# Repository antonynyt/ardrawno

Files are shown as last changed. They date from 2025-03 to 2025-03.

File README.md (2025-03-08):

# ArDRAWno: Dessinons!

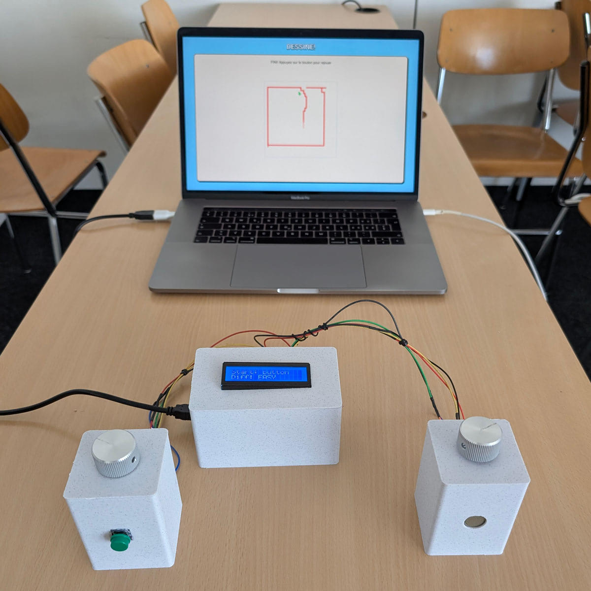
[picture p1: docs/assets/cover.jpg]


Réalisé par Antony Neyret
Option Arduino 2025 – COMEM+

---

## Description

Un jeu collaboratif difficile Ardunio où il faut dessiner une forme donnée. Des petits modules ou controlleurs permettent de dessiner sur le canvas affiché sur une page web.

La difficulté varie selon la communication des joueurs.

## Documentation

Retrouvez la documentation dans le dossier [docs](docs/).

## Photos

https://github.com/user-attachments/assets/9016710e-096b-463b-923a-413ef48c173d

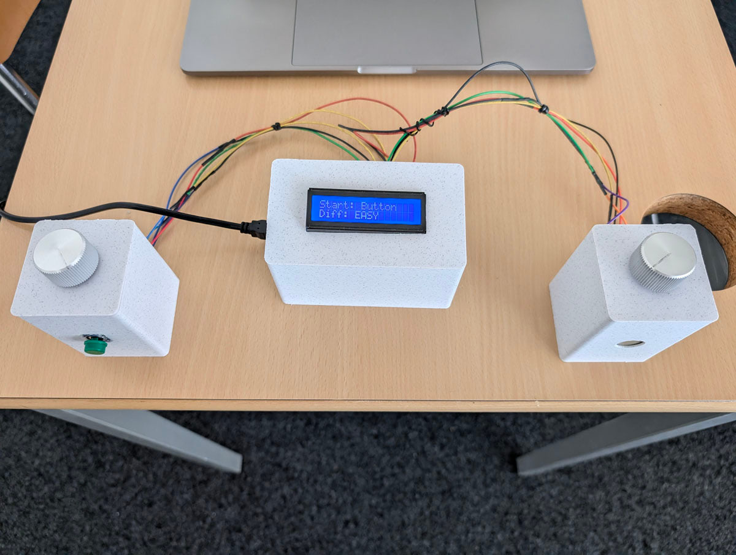
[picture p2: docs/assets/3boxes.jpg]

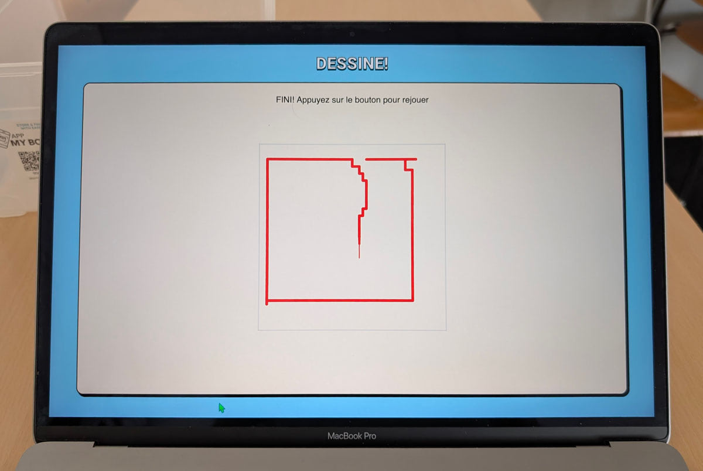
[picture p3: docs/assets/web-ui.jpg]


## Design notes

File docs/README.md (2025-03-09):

# Documentation

## Recherche et conception

Le plus important dans une école et aussi en général, c'est d'avoir une bonne entente avec autrui, communiquer et collaborer. C'est pour cette raison que j'ai eu envie de créer un jeu où il n'y a pas de gagnants ou de compétition mais de l'entraide. Pour renforcer les liens et briser la glace, il faut dessiner en suivant un modèle.

Mon objectif était de proposer une expérience utilisateur originale, volontairement imparfaite mais amusante.

### Inspirations

Je me suis principalement inspiré du jeu _Etch A Sketch_ et de sa méthode particulière de dessiner : deux boutons à tourner qui contrôlent l'axe vertical et horizontal. Je me suis aussi inspiré du jeu _Dessiner c'est gagné_.

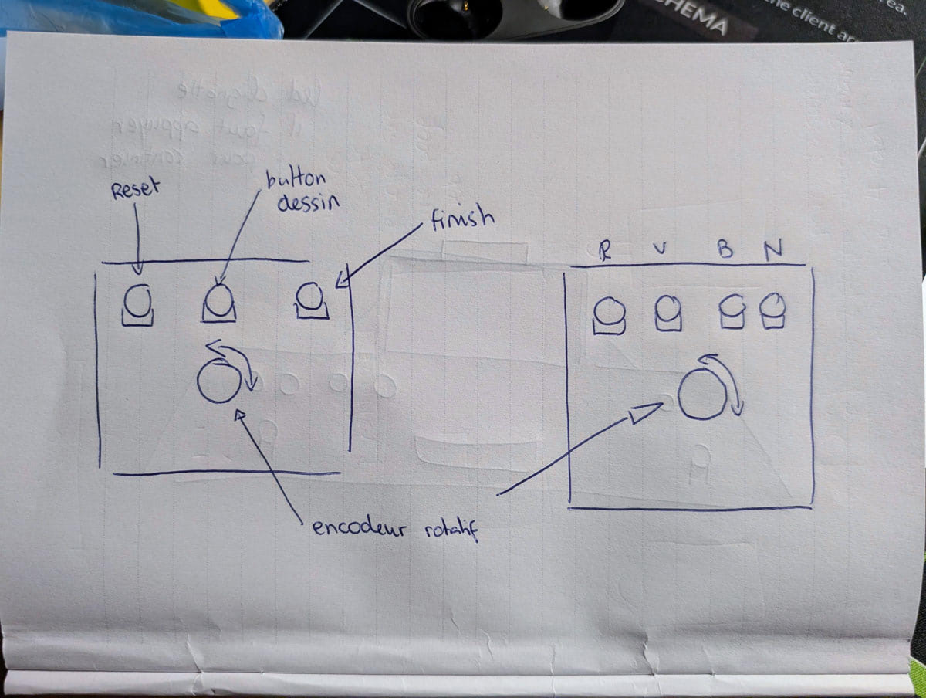
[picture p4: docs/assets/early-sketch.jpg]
Sketch de 2 boitiers: pour les couleurs et boutons rotatifs


J'ai testé plusieurs PoC. Un labyrinthe et le dessin. Le dessin s'est révélé plus amusant.

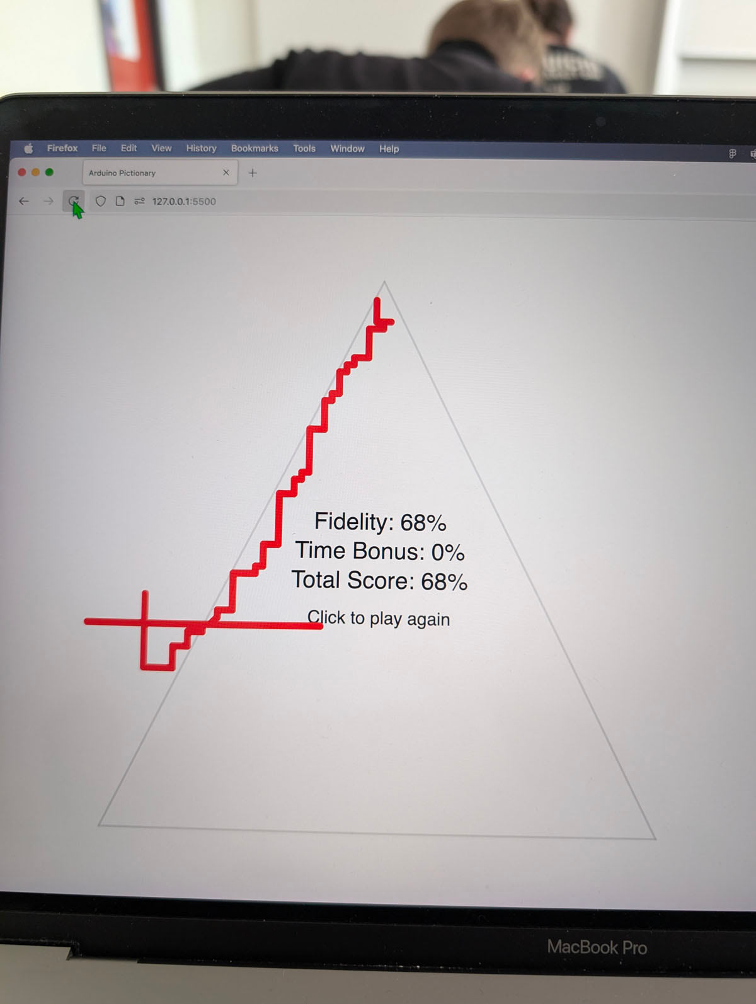
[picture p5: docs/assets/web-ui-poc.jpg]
Traits tramblant qui forme la moitié d'un triangle


Avec ce projet, je voulais aussi explorer la modélisation et l'impression 3D.

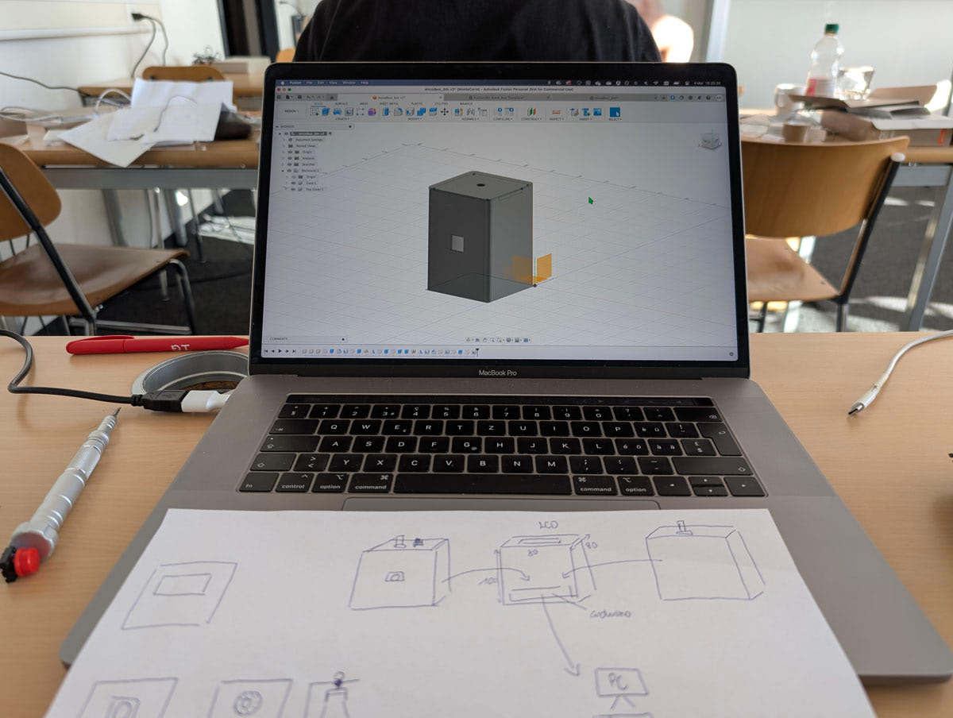
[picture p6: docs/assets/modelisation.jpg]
Modelisation du boitier sur Fusion


Vous trouvez les fichiers 3D [ici](/docs/assets/3D)
J'ai utilisé le model partagé par Andreas Spiess dans [cette video](https://youtu.be/lBK0UBjVrYM?si=KpptlfG_JRg5g7lZ).

## Circuit électronique

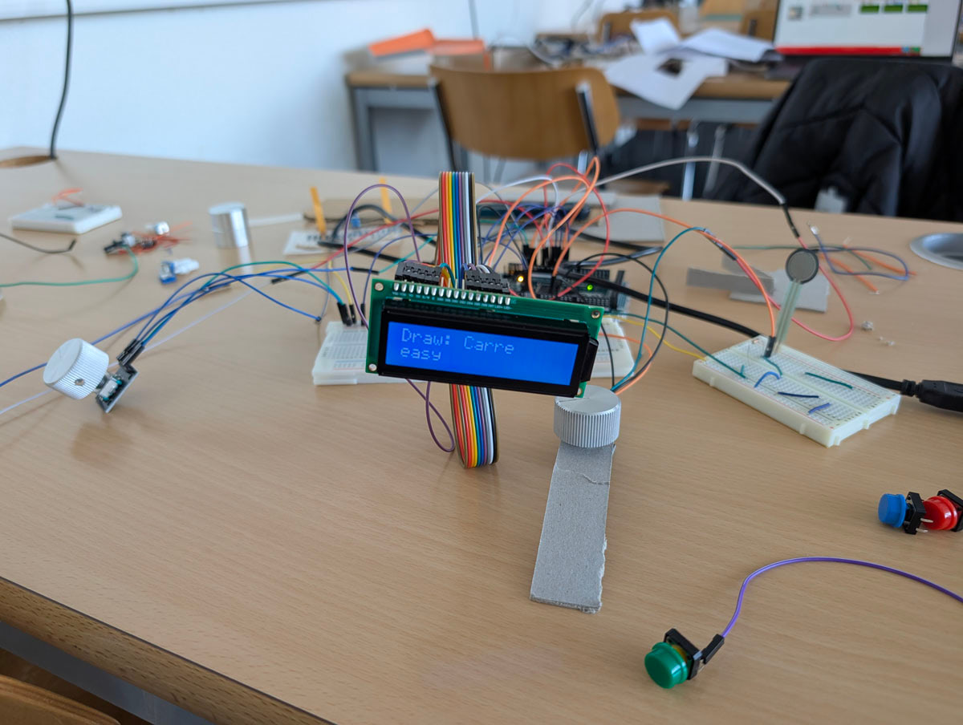
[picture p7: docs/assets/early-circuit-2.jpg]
circuit sur breadboard avec écran LCD écrit Draw: carré


Le circuit utilise principalement les composants suivants:
- **Arduino Mega 2560**: Initialement, je voulais connecter un écran. J'aurais eu besoin de plus de broches digital, d'où le choix de la Mega.
- **Écran LCD 16x2**: Affiche les instructions, le modèle à dessiner et le temps restant
- **Encodeurs rotatifs KY-040**: Permettent de contrôler les positions X et Y du curseur de dessin
- **Capteur de force FSR402**: Détecte la pression appliquée pour modifier l'épaisseur du trait
- **Bouton poussoir**: Permet de démarrer le jeu et d'activer/désactiver le dessin

### Schéma

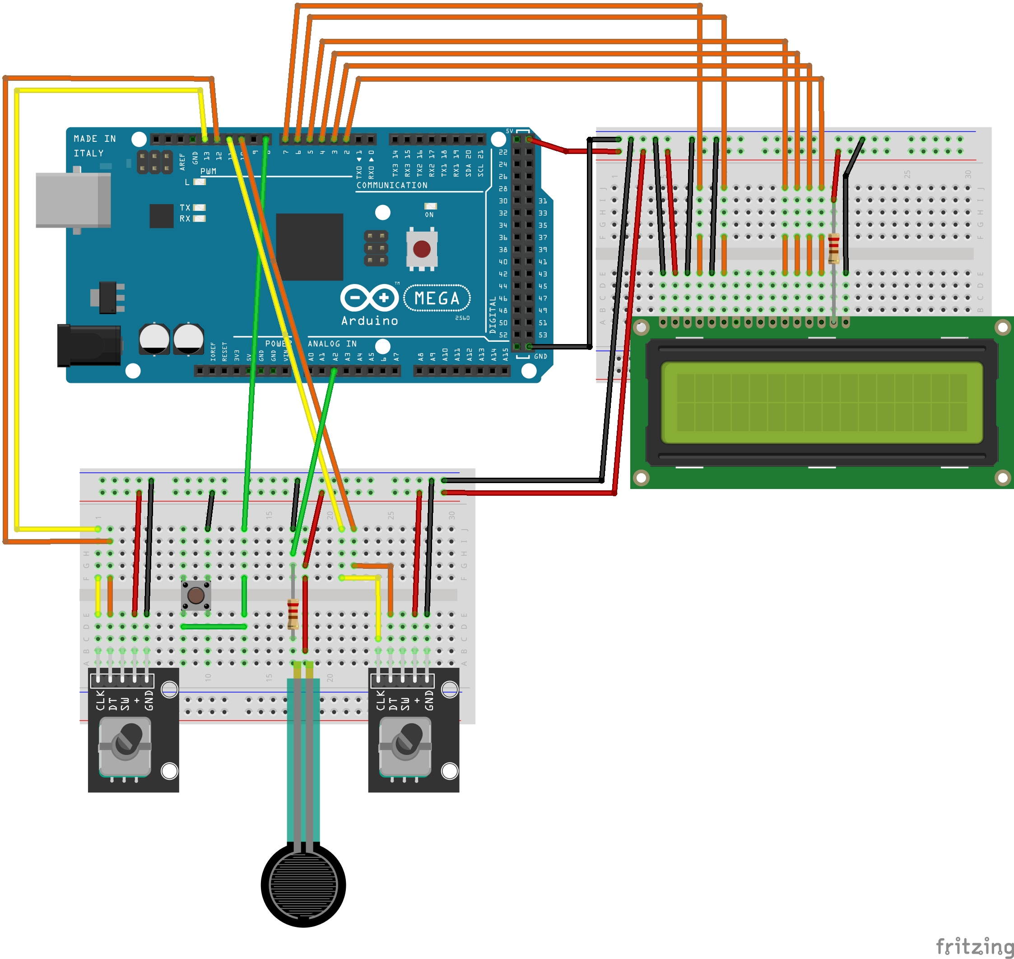
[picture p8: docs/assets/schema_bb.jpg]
Description de l'image


### BOM

| Réf | Composant | Quantité | Description | Fournisseur / Lien |
| --- | --- | --- | --- | --- |
| 1 | Arduino Mega 2560 | 1 | Microcontrôleur ATmega2560 | [Arduino](https://store.arduino.cc/products/arduino-mega-2560-rev3) |
| 2 | Breadboard | 3 | Plaque de prototypage | |
| 3 | KY-040 | 2 | Encodeur Rotatif | [BastelGarage](https://www.bastelgarage.ch/encodeur-rotatif-ky-040) |
| 4 | FSR402 | 1 | Capteur de force | |
| 5 | Button | 1 | Bouton avec un cache de couleur | |

## Programme

Le programme se divise en deux parties principales :

1. Arduino
2. Interface Web

### Arduino
Il gère la lecture des capteurs et communique avec l'interface web via le port série.

Pour l'écran LCD, j'ai utiliser la [docs](https://docs.arduino.cc/learn/electronics/lcd-displays/) de arduino et la librairie [LiquidCrystal](https://docs.arduino.cc/libraries/liquidcrystal/).

Concernant les encodeurs rotatif, j'ai suivi ce [tutoriel](https://sensorkit.joy-it.net/fr/sensors/ky-040) pour l'implémenter. J'ai eu de la peine à gérer les variations lors de la rotation.

### Interface Web
Elle affiche le canevas de dessin et interprète les données reçues de l'Arduino.

Le programme est réalisé en HTML, CSS et JavaScript avec la librairie p5.js. J'utilise la version desktop de p5.serialControl.

### Marche à suivre

1. Connecter le Arduino et lancer p5.serialControl.
2. Modifiez le fichier `/web/classes/constants.js` pour indiquer le port USB correct:
   ```javascript
   const SERIAL_PORT = '/dev/tty.usbmodem14201'; // Remplacez par votre port
   ```
2. Ouvrir le jeu web dans le navigateur, avec liveServer de VScode (par exemple).
3. Dessiner!

Retrouvez le guide d'installation complet pour modifier le projet dans le fichier [INSTALLATION.MD](/docs/INSTALLATION.md).

### Contrôles

- Button: Permet de dessiner et démarrer le jeu
- L'encodeur sur le boîtier du capteur de pression permet de choisir la difficulté.
- Force sensor: Controle l'épaisseur du trait
- Encodeurs rotatifs: Controle la position X et Y du trait.

## Roadmap et améliorationns

- Un bug d'affichage sur le LCD : la difficulté est affichée avec des lettres aléatoires.
- Actuellement, le jeu n'a pas de fin définie. Les dessins sont envoyés sur une page web, ce qui permet de conserver une trace sous forme de galerie.
- L'interface web nécessitera une amélioration de l'UI et de l'UX pour mieux expliquer ce qui se passe.

Je souhaitais afficher le timer sur l'écran LCD, mais cela bloque le dessin. Il y a également un problème d'accentuation, qui pourrait être résolu en créant des caractères personnalisés. C'est aussi de cette manière que je voulais implémenter le timer : sous forme de barre de chargement.

Un algorithme de reconnaissance de dessins pour attribuer un score était prévu. Il s'est avéré trop compliqué à mettre en place. Ce point pourrait être amélioré ultérieurement.

Dans le futur, l'idéal serait que la "console" soit indépendante du PC, par exemple avec un Raspberry Pi en mode kiosque ou un ESP32. Je verrais également ce jeu sous une forme modulaire. En connectant davantage de petits modules capteurs, le dessin évoluerait avec de nouvelles fonctionnalités. Par exemple, on pourrait ajouter un module de couleurs ou un autre module permettant d'ajouter une dimension pour passer en 3D.

Enfin, il serait intéressant d'envoyer les dessins sur une page web afin de constituer une galerie regroupant toutes les créations.

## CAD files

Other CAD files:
docs/assets/3D/arduino_LED.f3d
docs/assets/3D/encodeur_btn.f3d
docs/assets/3D/encodeur_pression.f3d

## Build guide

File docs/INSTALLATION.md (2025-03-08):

# Guide d'installation

Ce document explique comment installer et configurer le projet.

## Prérequis

- Arduino IDE (version 1.8.x ou supérieure)
- [p5.serialcontrol](https://github.com/p5-serial/p5.serialcontrol/releases) pour la communication série
- Un navigateur web

## Installation matérielle

1. Assemblez le circuit selon le schéma fourni dans la documentation principale
2. Connectez l'Arduino à votre ordinateur via USB

## Installation logicielle

### Arduino

1. Ouvrez Arduino IDE
2. Installez les bibliothèques requises via le gestionnaire de bibliothèques:
   - LiquidCrystal

3. Ouvrez le fichier sketch `main.ino`
4. Sélectionnez le bon port et le modèle de carte (Arduino Mega 2560)
5. Téléversez le programme sur la carte

### Interface Web

1. Installez p5.serialcontrol
2. Dans p5.serialcontrol, ouvrez le port correspondant à votre Arduino
3. Ouvrez le fichier `index.html` dans un serveur web local (comme Live Server de VSCode)

## Configuration

Modifiez le fichier `/web/classes/constants.js` pour indiquer le port USB correct:
   ```javascript
   const SERIAL_PORT = '/dev/tty.usbmodem14201'; // Remplacez par votre port
   ```

## Dépannage

- **Problème**: Pas de connexion série, l'interface web ne réagit pas
  **Solution**: Vérifiez que p5.serialcontrol est lancé et que le bon port est sélectionné (dans le fichier `/web/classes/constants.js` aussi), relancez le programme p5.serialcontrol et essayer de débrancher/rebrancher le Arduino.

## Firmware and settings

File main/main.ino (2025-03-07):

#include <LiquidCrystal.h>

// LCD pin definitions
#define LCD_RS 7
#define LCD_EN 6
#define LCD_D4 5
#define LCD_D5 4
#define LCD_D6 3
#define LCD_D7 2
#define BUFFER_SIZE 64
#define FSR_THRESHOLD 10
#define BUTTON_PIN 8 // draw and start button pin
const int FSR_PIN = A2; // force sensitive resistor pin

enum GameState {
  WAITING_FOR_START,
  RUNNING
};

struct GameInfo {
  char word[20];
  char difficulty[12];
  bool hasNewData;
};

struct Encoder {
  int pin_clk; // Clock pin is the pin that sends the signal to the microcontroller when the encoder is rotated.
  int pin_dt; // Data pin is the pin that sends the signal to the microcontroller when the encoder is rotated.
  int counter;
  bool direction;
  int last_clk;
};

int oldFsr = 0, oldBtnState = 0;

LiquidCrystal lcd(LCD_RS, LCD_EN, LCD_D4, LCD_D5, LCD_D6, LCD_D7);

Encoder encoders[] = {
  {13, 12, 0, true, 0},  // leftEncoder
  {11, 10, 0, true, 0}   // rightEncoder
};

const int numEncoders = 2;
int encoderValues[numEncoders] = {0}; // Stocke les valeurs pour affichage unique

const char* difficultyLevels[] = {"EASY", "MEDIUM", "HARD"};
const int numDifficulties = 3;
int currentDifficultyIndex = 0; // Default to EASY
int oldDifficultyIndex = -1;

GameInfo gameInfo = {"", difficultyLevels[currentDifficultyIndex], false};
GameState gameState = WAITING_FOR_START;

// Buffer for serial input
// holds chars as they arrive one by one from the serial connection
// allows to collect partial messages until a complete command is received, rather than processing one character at a time
char inputBuffer[BUFFER_SIZE];
int bufferIndex = 0; // Increments as each character is added to the buffer

void setup() {
  Serial.begin(9600);

  pinMode(BUTTON_PIN, INPUT_PULLUP);
  pinMode(FSR_PIN, INPUT);

  lcd.begin(16, 2); //init LCD
  displayWaitingMessage();

  // Init all encoders
  for (int i = 0; i < numEncoders; i++) {
    initEncoder(encoders[i]);
  }
}

void loop() {
  // Process any incoming serial data
  processSerial(gameInfo);
  
  // Check button state for game start
  int buttonState = !digitalRead(BUTTON_PIN);
  
  switch (gameState) {
    case WAITING_FOR_START:
      updateDifficultySelection();

      if (buttonState && !oldBtnState) {
        gameState = RUNNING;
        displayMessage("REGARDEZ L'ECRAN");
        delay(1000);
        Serial.print("START:"); // start with difficulty level
        Serial.println(difficultyLevels[currentDifficultyIndex]);
      }
      break;
      
    case RUNNING:
      sendSensorData(buttonState);
      if (gameInfo.hasNewData) {
        displayGameInfo(gameInfo.word, gameInfo.difficulty); //update LCD
        gameInfo.hasNewData = false;
      }
      break;
  }
  
  oldBtnState = buttonState;
}

void sendSensorData(int buttonState) {
  bool valueChanged = false;

  // Encoder change detection
  for (int i = 0; i < numEncoders; i++) {
    int oldValue = encoderValues[i];
    updateEncoder(encoders[i], encoderValues[i]);

    if (encoderValues[i] != oldValue) {
      valueChanged = true;
    }
  }

  // FSR change detection
  int fsrValue = analogRead(FSR_PIN);
  if (abs(fsrValue - oldFsr) > FSR_THRESHOLD) {
    valueChanged = true;
    oldFsr = fsrValue;
  }

  if (valueChanged || buttonState != oldBtnState) {
    Serial.print("DATA:");
    Serial.print(encoderValues[0]); // Left encoder
    Serial.print(",");
    Serial.print(encoderValues[1]); // Right encoder
    Serial.print(",");
    Serial.print(buttonState);
    Serial.print(",");
    Serial.println(fsrValue);
  }
}

// Rotary Encoder implementation
void initEncoder(Encoder &enc) {
  pinMode(enc.pin_clk, INPUT_PULLUP);
  pinMode(enc.pin_dt, INPUT_PULLUP);
  enc.last_clk = digitalRead(enc.pin_clk);
}

void updateEncoder(Encoder &enc, int &storedValue) {
  int current_clk = digitalRead(enc.pin_clk);
  
  // A change indicates the encoder is rotating
  if (current_clk != enc.last_clk) {
    delayMicroseconds(800);
    current_clk = digitalRead(enc.pin_clk); //to ensure stable reading after debounce
    
    if (digitalRead(enc.pin_dt) != current_clk) {  // detect clockwise rotation
      enc.counter++;
      enc.direction = true;
    } else {       
      enc.counter--;
      enc.direction = false;
    }
    storedValue = enc.counter;
  }
  enc.last_clk = current_clk; 
}

//LCD implementation
// ----------------

void displayMessage(const char* message) {
  lcd.clear();
  lcd.setCursor(0, 0);
  lcd.print(message);
}

void displayWaitingMessage() {
  lcd.clear();
  lcd.setCursor(0, 0);
  lcd.print("Start: Button");
  lcd.setCursor(0, 1);
  lcd.print("Diff: ");
  lcd.print("EASY");
}

void updateDifficultySelection() {
  // Store previous value to detect changes
  int oldValue = encoderValues[0];
  
  // Use the existing updateEncoder function
  updateEncoder(encoders[0], encoderValues[0]);
  
  // Only process if encoder value has changed
  if (encoderValues[0] != oldValue) {
    // Save previous difficulty for display comparison
    oldDifficultyIndex = currentDifficultyIndex;
    
    // Determine if rotation was clockwise or counterclockwise
    if (encoderValues[0] > oldValue) {
      // Clockwise - move to next difficulty
      currentDifficultyIndex = (currentDifficultyIndex + 1) % numDifficulties;
    } else {
      // Counterclockwise - move to previous difficulty
      // Add numDifficulties before modulo to ensure positive value
      currentDifficultyIndex = (currentDifficultyIndex - 1 + numDifficulties) % numDifficulties;
    }
    
    // Update gameInfo with the new difficulty
    strcpy(gameInfo.difficulty, difficultyLevels[currentDifficultyIndex]);
    
    // Update LCD display with new difficulty
    lcd.setCursor(6, 1);
    lcd.print(difficultyLevels[currentDifficultyIndex]);
    lcd.print("  "); // Clear any remaining characters
  }
}

void displayGameInfo(const char* word, const char* difficulty) {
  lcd.clear();
  lcd.setCursor(0, 0);
  lcd.print("Draw: ");
  lcd.print(word);
  lcd.setCursor(0, 1);
  lcd.print(difficulty);
}

// Incoming serial processing implementation
// ----------------

void processSerial(GameInfo& gameInfo) {
  if (Serial.available() > 0) {
    while (Serial.available() > 0) {
      char c = Serial.read();
      
      // Adds characters to the buffer until it receives a newline character
      if (c != '\n' && bufferIndex < BUFFER_SIZE - 1) {
        inputBuffer[bufferIndex++] = c;
      } 
      // End of message, process it
      else {
        inputBuffer[bufferIndex] = '\0'; // Null-terminate the string
        parseSerialData(inputBuffer, gameInfo);
        bufferIndex = 0; // Reset buffer
      }
    }
  }
}

// Parse incoming serial data
void parseSerialData(char* buffer, GameInfo& gameInfo) {
  // Check if string is 6 characters long and starts with "SHAPE:"
  if (strncmp(buffer, "SHAPE:", 6) == 0) {
    // Copy the word into the game info struct
    strncpy(gameInfo.word, buffer + 6, sizeof(gameInfo.word) - 1);
    gameInfo.hasNewData = true;
  }
  // Check if string is 5 characters long and starts with "DIFF:"
  else if (strncmp(buffer, "DIFF:", 5) == 0) {
    strncpy(gameInfo.difficulty, buffer + 5, sizeof(gameInfo.difficulty) - 1);
    gameInfo.hasNewData = true;
  }
  // If reset command
  else if (strncmp(buffer, "RESET", 5) == 0) {
    gameInfo.hasNewData = true;
    displayWaitingMessage();
    gameState = WAITING_FOR_START;
  }
}

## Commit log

2025-03-06 fix: game start immediately
    [main.ino]
2025-03-06 fix: issue in rotary encoder and fsr sensor
    [main.ino]
2025-03-06 add: fritzing schema
    [schema.fzz, schematics.fzz]
2025-03-09 docs: add 3d files
    [arduino_LED.f3d, encodeur_btn.f3d, encodeur_pression.f3d]
